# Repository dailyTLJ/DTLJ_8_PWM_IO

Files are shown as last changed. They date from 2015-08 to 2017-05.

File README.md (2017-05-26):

# DTLJ_8_PWM_IO
custom Arduino Mega Shield

8 Molex 4-c connectors, each connected to power, ground, PWM (2-9) and Analog Input (8-15)

## Version 2
Inline resistor (smd 1206) on PWM lines



## Version 3
Inline resistors (smd 1206) on PWM lines and pull-down resistors (smd 1206) on Analog input lines



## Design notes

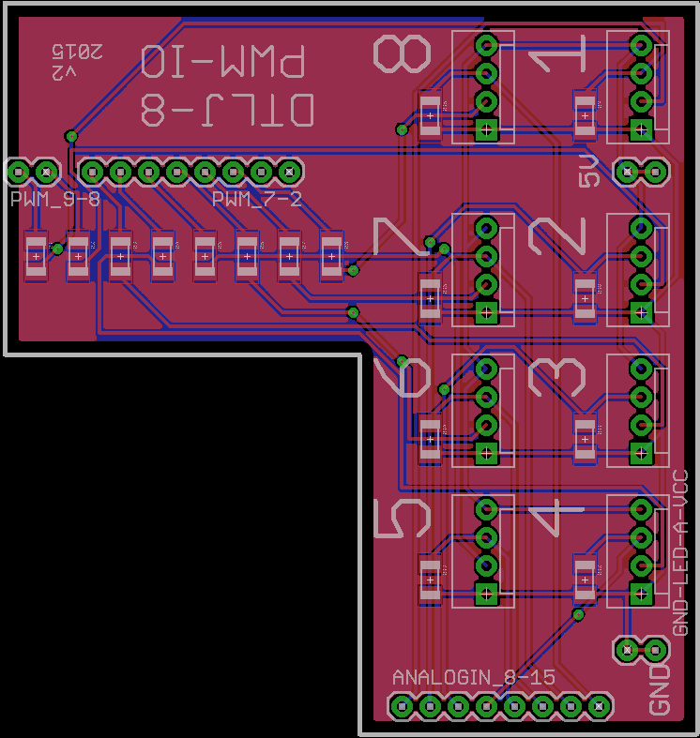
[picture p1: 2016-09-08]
mega_connector_shield_BRD_v3.png

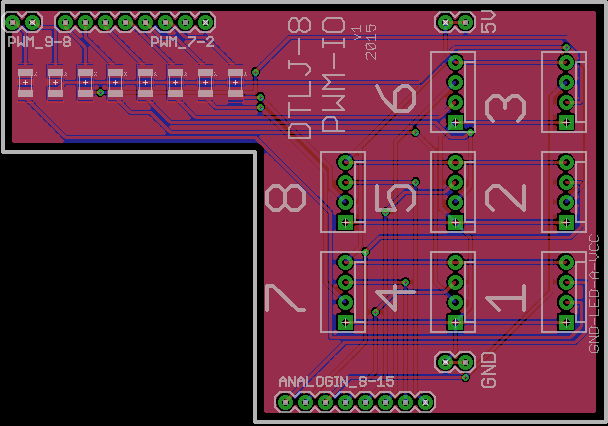
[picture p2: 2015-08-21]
mega_connector_shield_BRD_v2.png

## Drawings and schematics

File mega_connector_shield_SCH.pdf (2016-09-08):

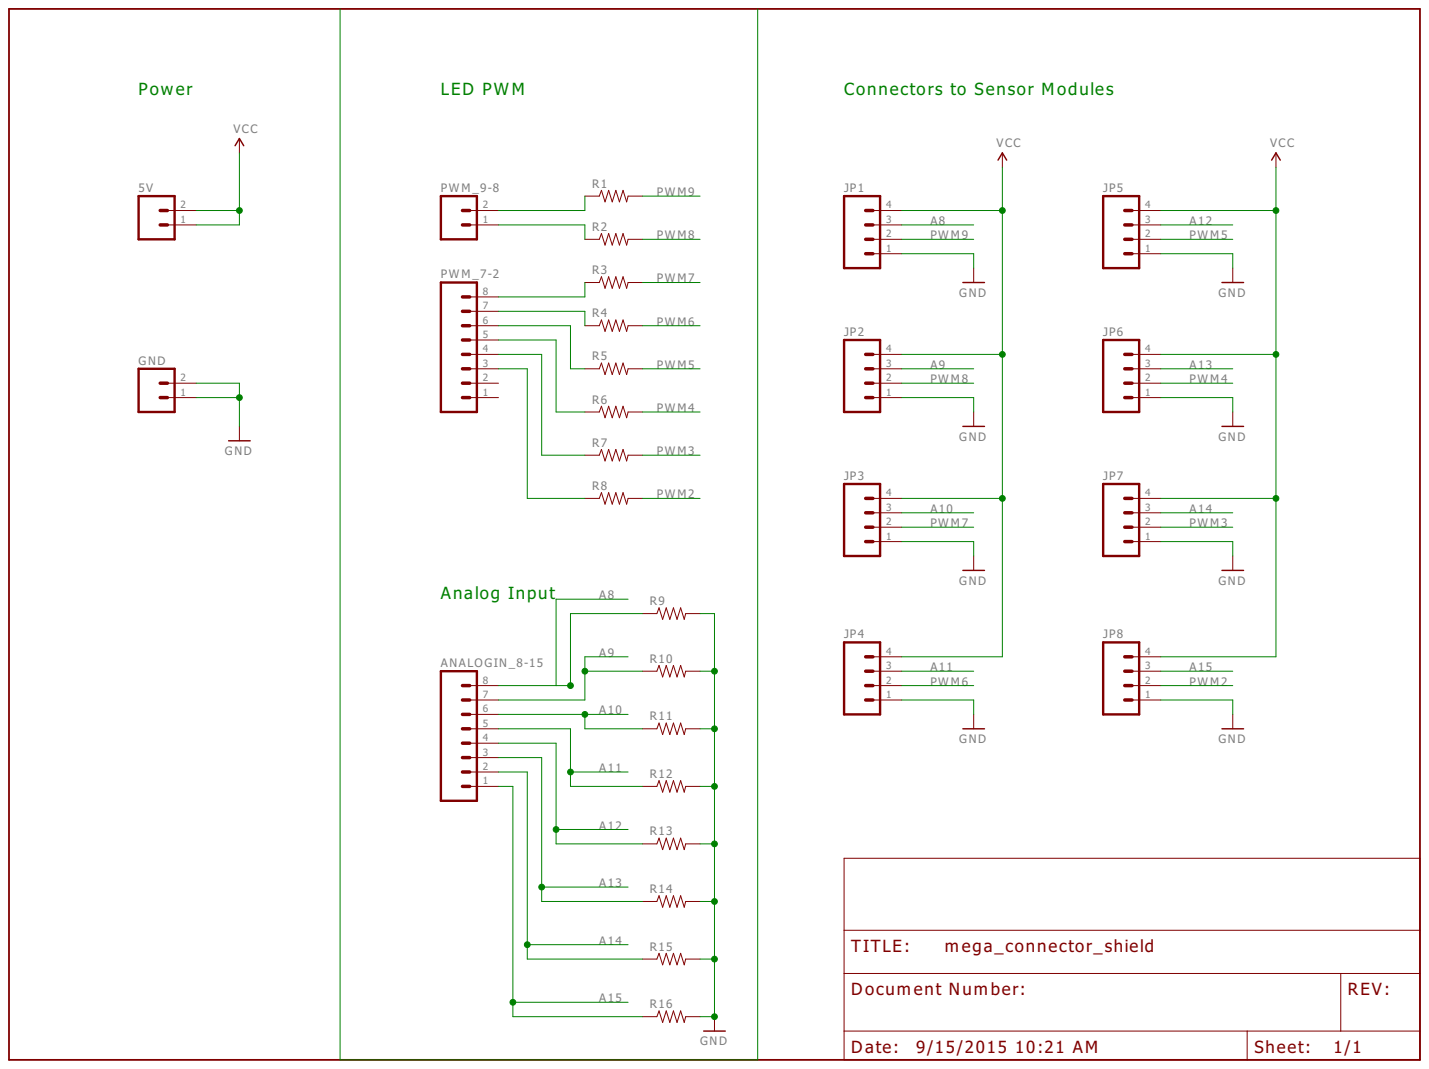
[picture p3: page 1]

Connectors to Sensor Modules

Document Number: | REV:

Date: 9/15/2015 10:21 AM | Sheet: 1/1

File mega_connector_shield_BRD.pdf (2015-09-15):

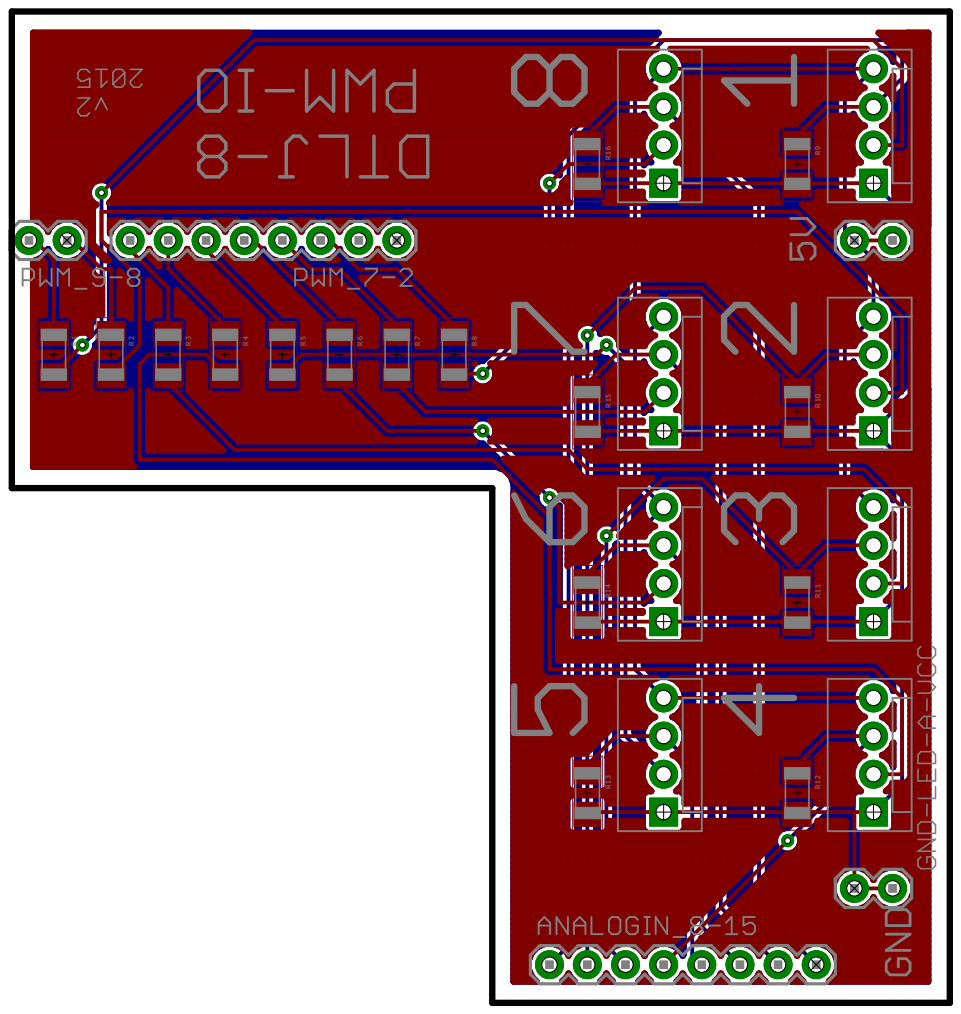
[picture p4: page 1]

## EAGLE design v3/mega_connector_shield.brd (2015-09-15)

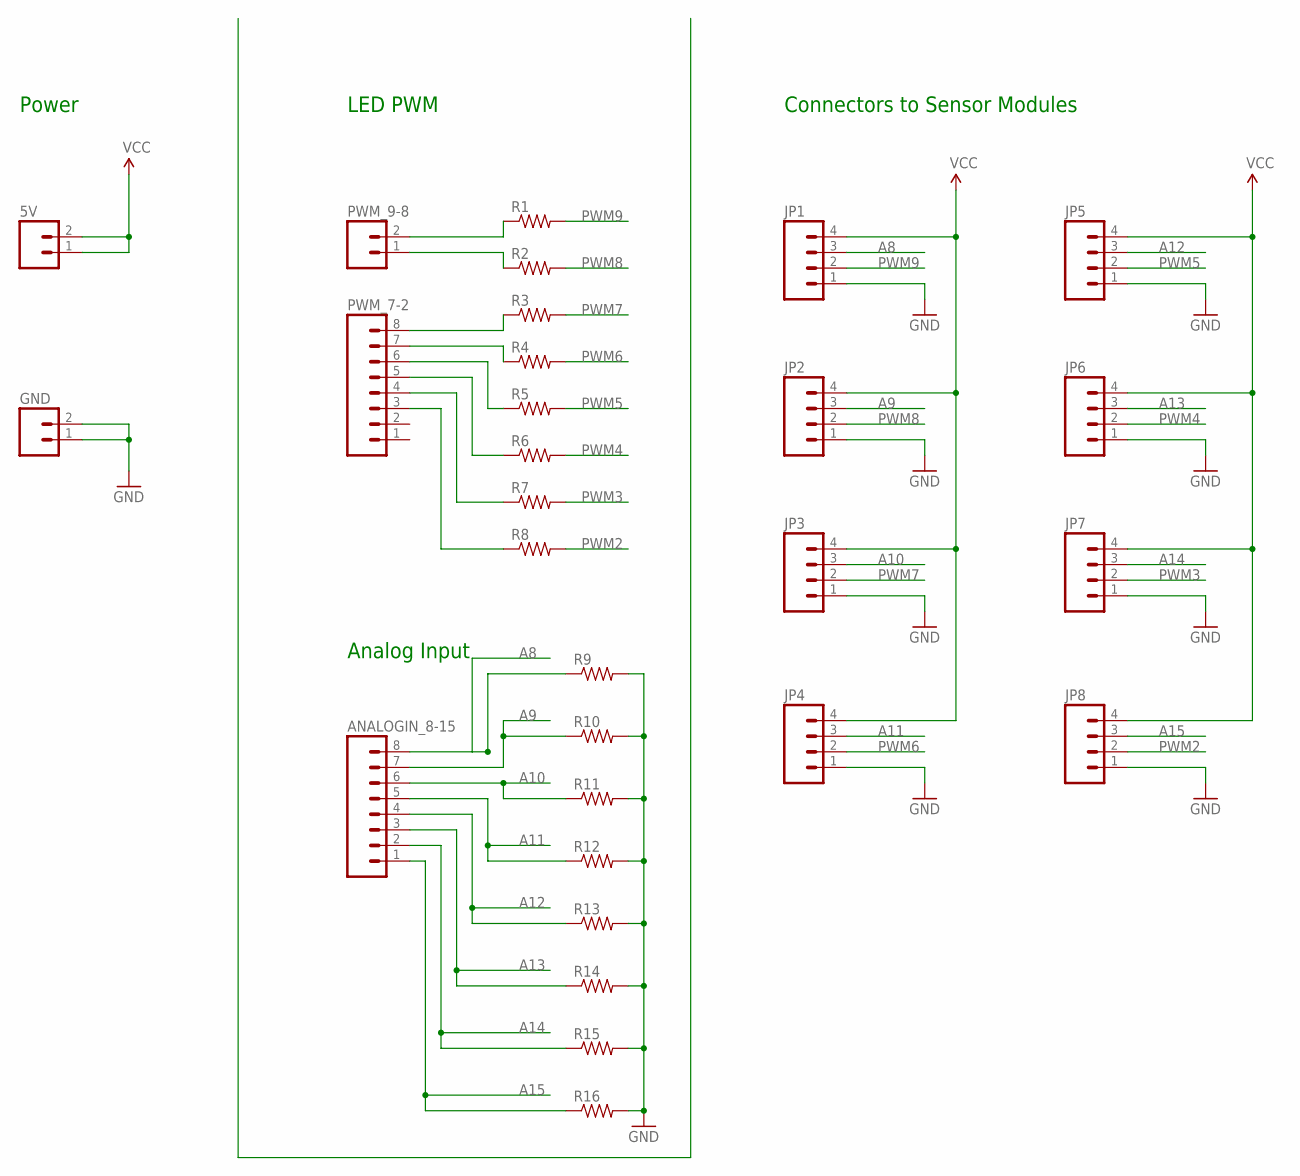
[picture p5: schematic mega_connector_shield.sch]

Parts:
5V: M02PTH; 1X02
ANALOGIN_8-15: M08; 1X08_ROUND
GND: M02PTH; 1X02
JP1, JP2, JP3, JP4, JP5, JP6, JP7, JP8: M04POLAR; MOLEX-1X4
PWM_7-2: M08; 1X08_ROUND
PWM_9-8: M02PTH; 1X02
R1, R2, R3, R4, R5, R6, R7, R8, R9, R10, R11, R12, R13, R14, R15, R16: RESISTOR1206; 1206

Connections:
A8: ANALOGIN_8-15.8, JP1.3, R9.1
A9: ANALOGIN_8-15.7, JP2.3, R10.1
A10: ANALOGIN_8-15.6, JP3.3, R11.1
A11: ANALOGIN_8-15.5, JP4.3, R12.1
A12: ANALOGIN_8-15.4, JP5.3, R13.1
A13: ANALOGIN_8-15.3, JP6.3, R14.1
A14: ANALOGIN_8-15.2, JP7.3, R15.1
A15: ANALOGIN_8-15.1, JP8.3, R16.1
GND: GND.1, GND.2, JP1.1, JP2.1, JP3.1, JP4.1, JP5.1, JP6.1, JP7.1, JP8.1, R9.2, R10.2, R11.2, R12.2, R13.2, R14.2, R15.2, R16.2
unnamed: PWM_9-8.2, R1.1
unnamed: PWM_9-8.1, R2.1
unnamed: PWM_7-2.8, R3.1
unnamed: PWM_7-2.7, R4.1
unnamed: PWM_7-2.6, R5.1
unnamed: PWM_7-2.5, R6.1
unnamed: PWM_7-2.4, R7.1
unnamed: PWM_7-2.3, R8.1
PWM2: JP8.2, R8.2
PWM3: JP7.2, R7.2
PWM4: JP6.2, R6.2
PWM5: JP5.2, R5.2
PWM6: JP4.2, R4.2
PWM7: JP3.2, R3.2
PWM8: JP2.2, R2.2
PWM9: JP1.2, R1.2
VCC: 5V.1, 5V.2, JP1.4, JP2.4, JP3.4, JP4.4, JP5.4, JP6.4, JP7.4, JP8.4

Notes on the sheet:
Power
LED PWM
Analog Input
Connectors to Sensor Modules

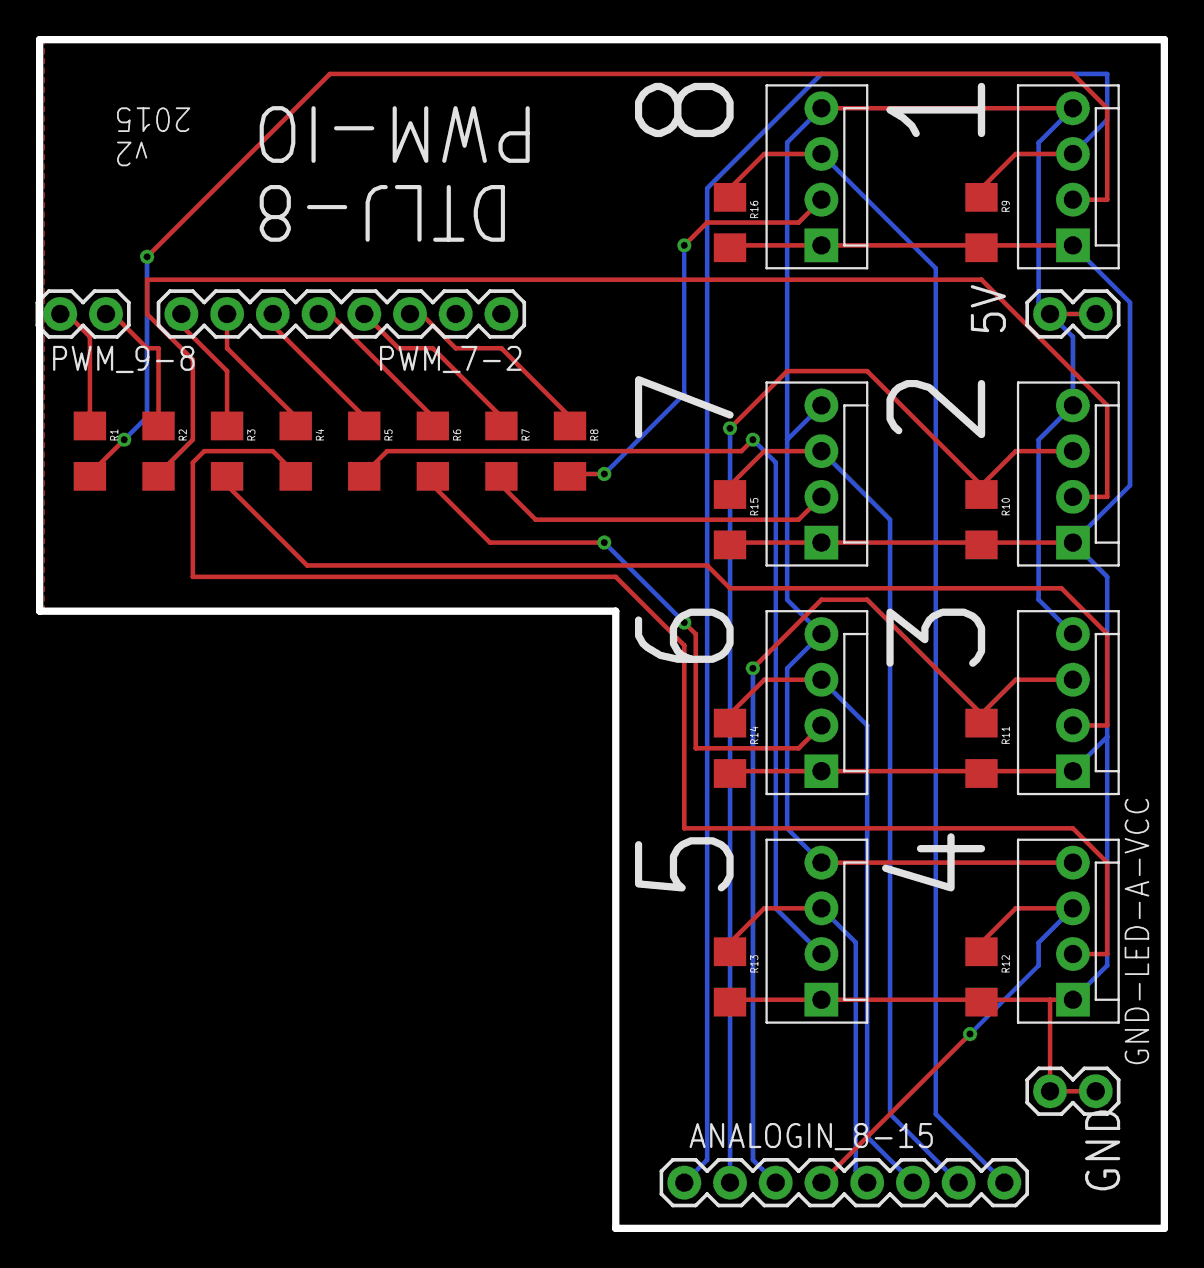
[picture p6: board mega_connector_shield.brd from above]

Board: 2 copper layers, 62.5 x 66.0 mm, 29 parts (0 on the bottom side), 26 nets.

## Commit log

2015-08-21 first version ready to order
    [mega_connector_shield.brd, mega_connector_shield.sch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]
2015-09-15 change shape, add sensor resistor here for pull-down when not connected
    [mega_connector_shield.brd, mega_connector_shield.sch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]
2016-09-08 board pngs and demo circuit of full sensor/led circuit
    [demo.sch]

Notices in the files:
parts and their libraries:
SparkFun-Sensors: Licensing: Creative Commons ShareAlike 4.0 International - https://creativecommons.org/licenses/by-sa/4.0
